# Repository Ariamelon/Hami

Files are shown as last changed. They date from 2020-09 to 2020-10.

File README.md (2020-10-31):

# Hami
 Simple numberpad with OLED and encoder support, nothing else to say really. Designed for use with a standard 0.91" SSD1306 OLED or the [Crenshaw](https://github.com/Ariamelon/Crenshaw) 1.3" OLED breakout board.

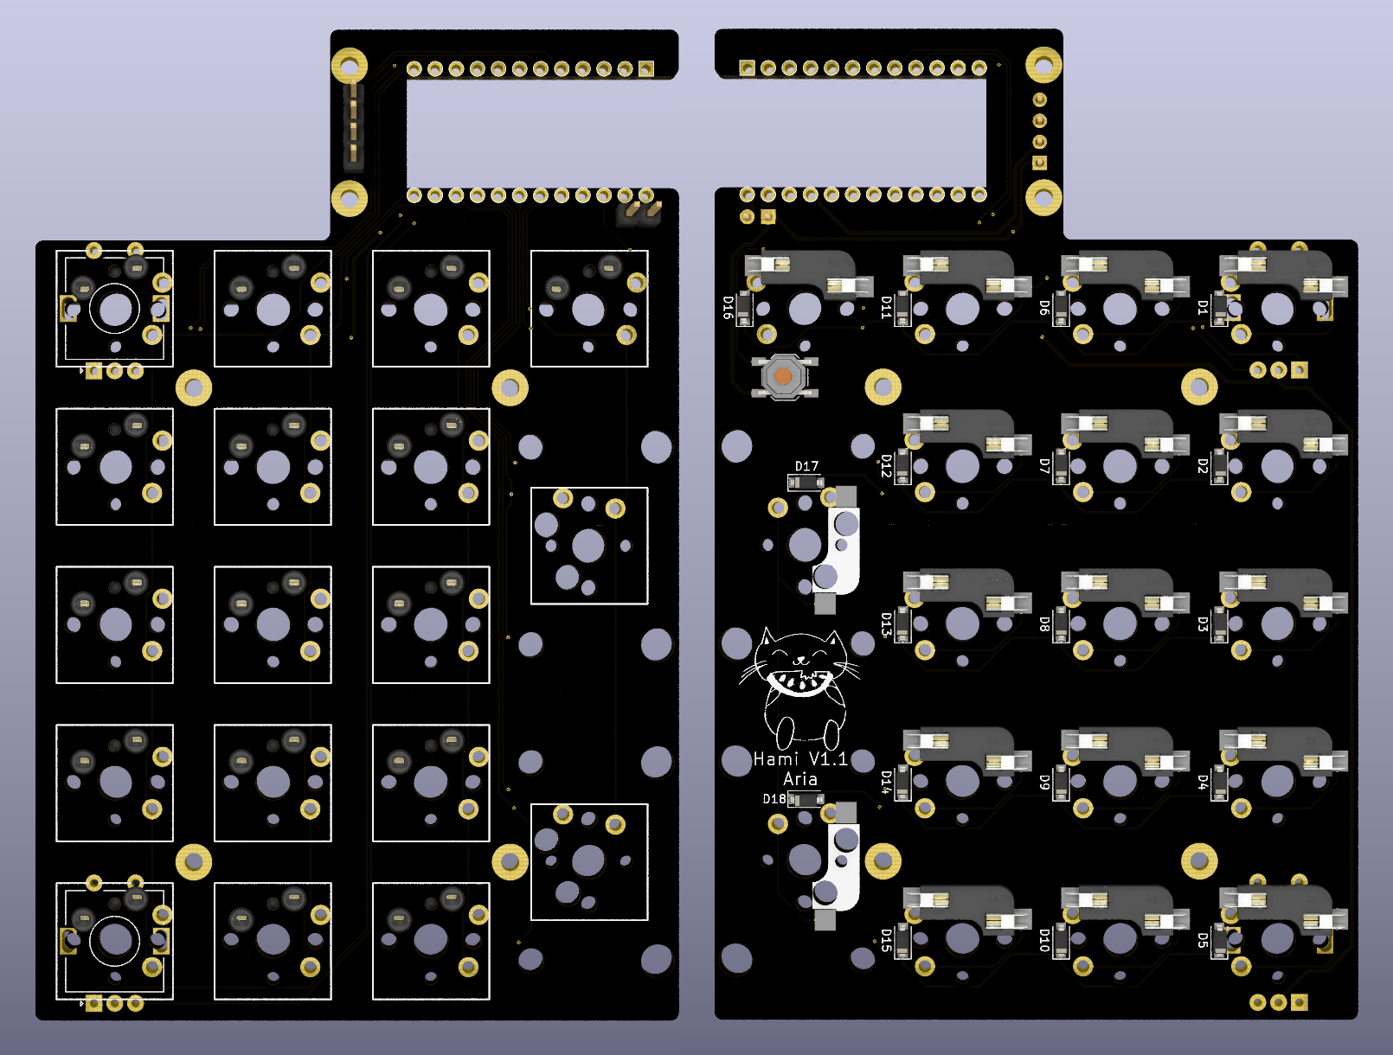
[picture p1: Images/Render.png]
Hami Render
 

 ## Changelog
 * 27/09/2020: Initial commit.
 * 28/09/2020: Added rotary encoder support.
 * 24/10/2020: Updated to V1.1. Moved position of OLED to allow for enough room and changed design of plate to compensate.

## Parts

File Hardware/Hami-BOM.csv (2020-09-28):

Name | Component | Package | Value | Qty
D1-D18 | Diode | SOD-123(F) | - | 18
J1 | Crenshaw OLED | 64x128 | SSD1306 | 1
R1 | Resistor | 0603 | 10k | 1
SW1 | Reset Switch | TL3342 | - | 2
SW2-SW19 | Kailh Hotswap Sockets | SMD | - | 18
SW20, SW21 | Rotary Encoder | EC11 |  | 2
SW32, SW65 | 5-way switch | 10x10x9 |  | 2
U1 | Pro Micro Sockets | Peelaway | 12 x 2.54mm | 2
Tray-mount case
- | Plate | - | - | 1
- | Standoff | M2 x 3H x 3.5D mm | - | 4
- | Standoff | M2 x 3.5H x 3.5D mm | - | 4
- | Screw | M2 x 3mm |  | 4
- | Screw | M2 x 6mm |  | 4
- | Tray |  |  | 1
Fully Wireless
- | LiPo Battery | 802030 | 400mAH | 1
OLED
- | OLED sockets | 4 x 2.54mm | 315-XX-XXX-41-003000 | 1
- | Standoff | M2 x 2.5H x 3.5D mm |  | 2
- | Screw | M2 x 6mm |  | 2
- | Screw | M2 x 3mm |  | 2

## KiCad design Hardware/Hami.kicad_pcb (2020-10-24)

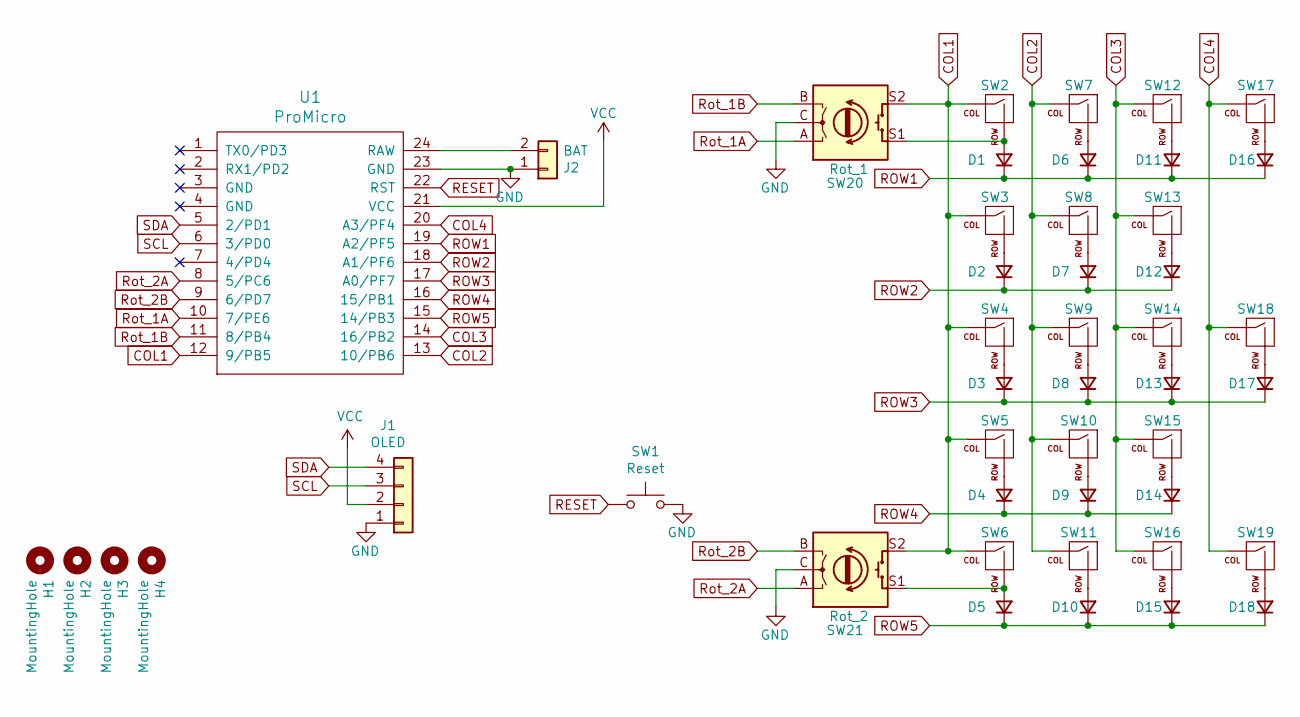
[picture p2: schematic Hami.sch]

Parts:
D1, D2, D3, D4, D5, D6, D7, D8, D9, D10, D11, D12, D13, D14, D15, D16, D17, D18: D; D_SOD-123
H1, H2, H3, H4: MountingHole; MountingHole_2.2mm_M2_Pad
J1: OLED; PinHeader_1x04_P2.54mm_Vertical_No_Silk
J2: BAT; Battery_Solder_Points
SW1: Reset; SW_SPST_TL3342
SW2, SW3, SW4, SW5, SW6, SW7, SW8, SW9, SW10, SW11, SW12, SW13, SW14, SW15, SW16, SW17: MX; CherryMX_Hotswap_SMK
SW18, SW19: MX; CherryMX_Hotswap_2u_SMK
SW20: Rot_1; RotaryEncoder_Alps_EC11E-Switch_Vertical_H20mm
SW21: Rot_2; RotaryEncoder_Alps_EC11E-Switch_Vertical_H20mm
U1: ProMicro; ArduinoProMicro_Blank

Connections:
COL1: SW2.1 (COL), SW3.1 (COL), SW4.1 (COL), SW5.1 (COL), SW6.1 (COL), SW20.S2, SW21.S2, U1.12 (9/PB5)
COL2: SW7.1 (COL), SW8.1 (COL), SW9.1 (COL), SW10.1 (COL), SW11.1 (COL), U1.13 (10/PB6)
COL3: SW12.1 (COL), SW13.1 (COL), SW14.1 (COL), SW15.1 (COL), SW16.1 (COL), U1.14 (16/PB2)
COL4: SW17.1 (COL), SW18.1 (COL), SW19.1 (COL), U1.20 (A3/PF4)
GND: J1.1, J2.1, SW1.2, SW20.C, SW21.C, U1.23 (GND)
unnamed: D1.2 (A), SW2.2 (ROW), SW20.S1
unnamed: D2.2 (A), SW3.2 (ROW)
unnamed: D3.2 (A), SW4.2 (ROW)
unnamed: D4.2 (A), SW5.2 (ROW)
unnamed: D5.2 (A), SW6.2 (ROW), SW21.S1
unnamed: D6.2 (A), SW7.2 (ROW)
unnamed: D7.2 (A), SW8.2 (ROW)
unnamed: D8.2 (A), SW9.2 (ROW)
unnamed: D9.2 (A), SW10.2 (ROW)
unnamed: D10.2 (A), SW11.2 (ROW)
unnamed: D11.2 (A), SW12.2 (ROW)
unnamed: D12.2 (A), SW13.2 (ROW)
unnamed: D13.2 (A), SW14.2 (ROW)
unnamed: D14.2 (A), SW15.2 (ROW)
unnamed: D15.2 (A), SW16.2 (ROW)
unnamed: D16.2 (A), SW17.2 (ROW)
unnamed: D17.2 (A), SW18.2 (ROW)
unnamed: D18.2 (A), SW19.2 (ROW)
unnamed: J2.2, U1.24 (RAW)
RESET: SW1.1, U1.22 (RST)
ROW1: D1.1 (K), D6.1 (K), D11.1 (K), D16.1 (K), U1.19 (A2/PF5)
ROW2: D2.1 (K), D7.1 (K), D12.1 (K), U1.18 (A1/PF6)
ROW3: D3.1 (K), D8.1 (K), D13.1 (K), D17.1 (K), U1.17 (A0/PF7)
ROW4: D4.1 (K), D9.1 (K), D14.1 (K), U1.16 (15/PB1)
ROW5: D5.1 (K), D10.1 (K), D15.1 (K), D18.1 (K), U1.15 (14/PB3)
Rot_1A: SW20.A, U1.10 (7/PE6)
Rot_1B: SW20.B, U1.11 (8/PB4)
Rot_2A: SW21.A, U1.8 (5/PC6)
Rot_2B: SW21.B, U1.9 (6/PD7)
SCL: J1.3, U1.6 (3/PD0)
SDA: J1.4, U1.5 (2/PD1)
VCC: J1.2, U1.21 (VCC)

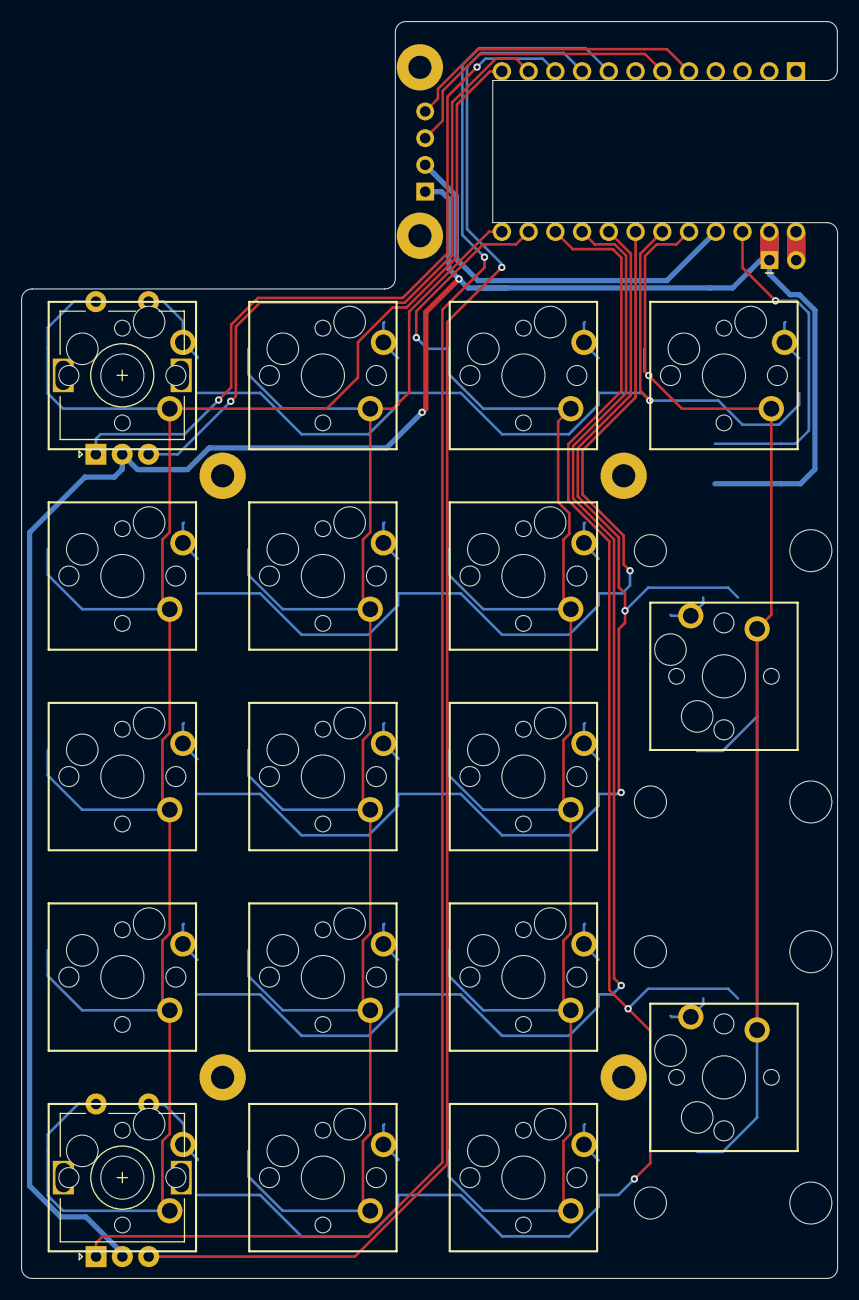
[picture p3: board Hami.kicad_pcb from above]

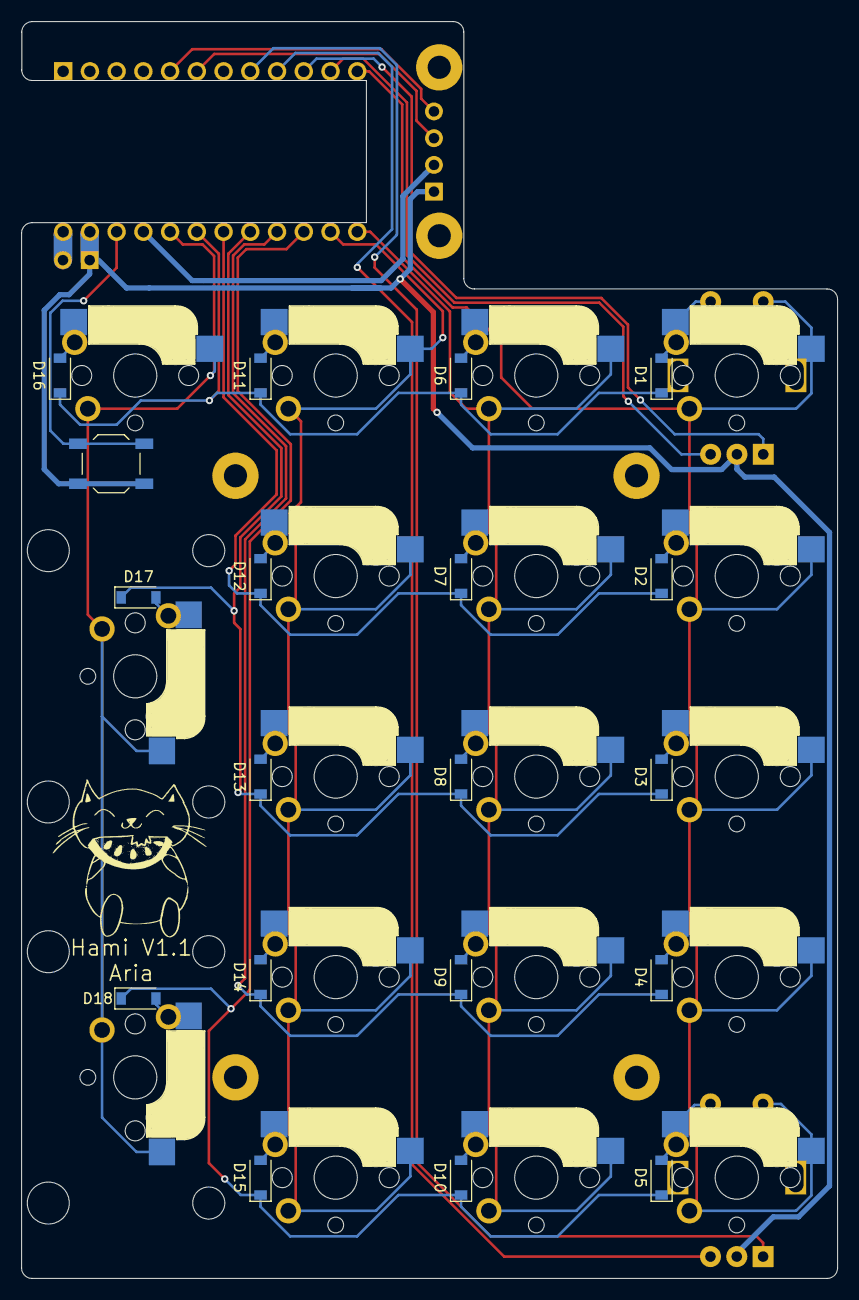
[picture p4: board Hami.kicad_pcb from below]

Board: 2 copper layers, 77.5 x 119.4 mm, 46 parts (19 on the bottom side), 37 nets.

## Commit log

2020-09-28 Hami V1.1
    Because who doesn't need rotary encoder support in the botton and top left corners? Also re-routed some of the traces.
    [Hami.kicad_pcb, Hami.sch]
2020-09-28 Proper case files and gerbers
    Added an STL file for a rudimentary 3D-printed case for the Hami as well as DXF and gerber files for a plate.
    [Hami-B_Cu.gbr, Hami-B_Mask.gbr, Hami-B_Paste.gbr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]
2020-09-28 Added BOM
    [Hami-BOM.csv, Hami-BOM.xlsx]
2020-10-01 Added renders and updated readme
    [Hami.kicad_pcb]
2020-10-02 Changed footprint references
    [Hami.kicad_pcb, Hami.sch]
2020-10-24 Moved position of OLED, added new plate
    [Hami-Base.kicad_pcb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]
